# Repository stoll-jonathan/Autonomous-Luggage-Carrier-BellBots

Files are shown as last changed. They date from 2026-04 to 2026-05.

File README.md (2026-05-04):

# BellBot — Autonomous Luggage Carrier

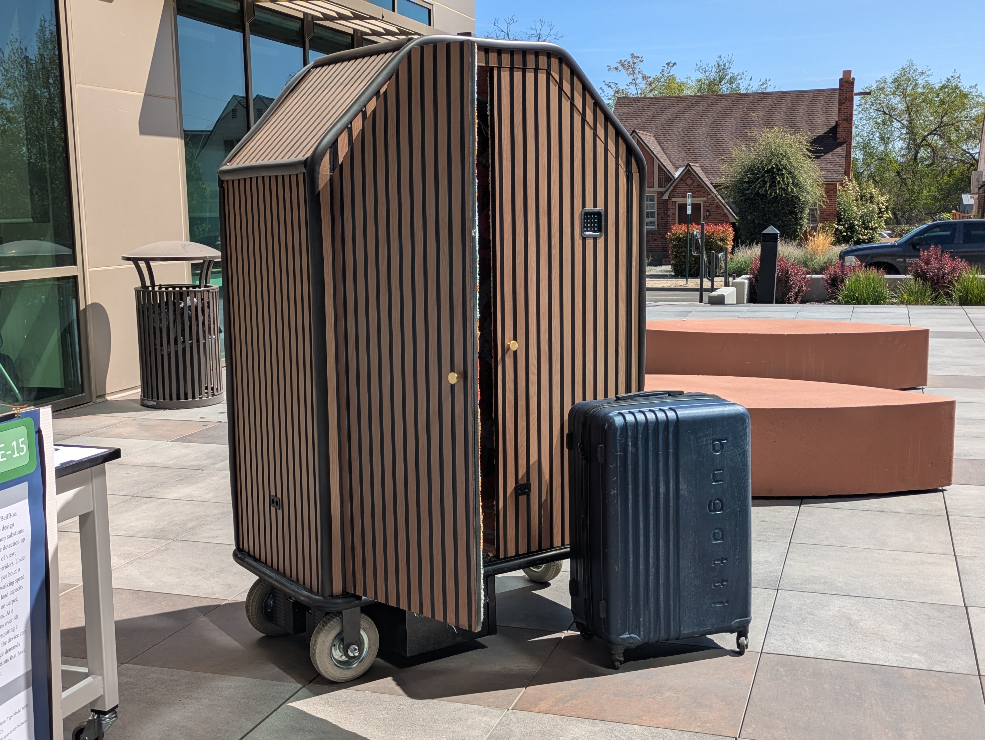
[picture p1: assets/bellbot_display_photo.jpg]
BellBot completed system


> **My role:** I designed and built the complete electronics, sensor integration, and autonomy software for this system. A team of 5 contributed the drive system and fabricated the housing.

---

## Overview

The BellBot autonomous luggage system addresses two pressing challenges in the hotel industry: guest luggage security and bell service operational cost. A guest checks in, their luggage is loaded into BellBot and secured via an electronic locking system, and the cart autonomously navigates to the guest's room, arriving ready to meet them.

With a projected unit cost of ~$2500, BellBot offers a compelling alternative to the ongoing labor cost of human bell staff.

---

## How It Works

BellBot is controlled by an Arduino running a C++ autonomy stack. At the core of the system:

- A **keypad interface** handles guest authentication and program selection
- An array of **ultrasonic sensors** provide obstacle detection to stop the cart safely if something enters its path
- An **electronic locking mechanism** secures the luggage compartment until the correct code is entered at the destination
- A **motor controller** interfaces between the Arduino and the drive system, translating autonomy commands into wheel movement

The system is designed around a simple state machine: the cart accepts a destination program, locks the compartment, navigates autonomously, and waits for authenticated unlocking at the destination.

---

## My Contributions

All code in this repository was written by me. My work on BellBot covered three areas:

**Electronics & Wiring** — Designed and wired the complete electronics system, including the Arduino, motor controller, ultrasonic sensors, keypad, and electronic lock. Designed the electronics enclosure and produced the full system wiring diagram and bill of materials for electronic components.

**Sensor Integration** — Wrote all processing code for the ultrasonic sensor data. Tuned detection thresholds and motor control logic for reliable real-world performance in a corridor environment.

**Autonomy Stack** — Implemented the sensor data processing, keypad input handling, navigation programs, and motor control interface in C++. Designed the demo program suite for testing and demonstration purposes.

> 📂 Full portfolio write-up with circuit diagrams, wiring photos, and CAD files: [sites.google.com/view/JonathanLukeStoll](#)

---

## Demo Programs

The system ships with five navigation programs selectable via keypad at startup. These were designed to test and demonstrate the key movement capabilities of the BellBot device.

| Keystring | Program | Description |
|---|---|---|
| `1972` | Unlock Door | Electronic lock retracts. Compartment can be locked again with any four digits which are not already a stated input code. |
| `#A11` | Stop on Detection | Cart advances until an obstacle is detected by the ultrasonic sensors, then halts |
| `#B22` | Turn Left | Executes a calibrated 90° left turn |
| `#C33` | Turn Right | Executes a calibrated 90° right turn |
| `#D44` | Turn 180 | Executes a full calibrated 180° turn |
| `BBBB` | Move Backward | Reverses for five seconds |

Enter `####` at any time to stop the current program.

---

## Hardware

| Component | Role |
|---|---|
| Arduino Mega | Main computer and autonomy controller |
| Ultrasonic sensors | Obstacle detection |
| Matrix keypad | Guest authentication and program selection |
| Electronic lock | Luggage compartment security |
| Motor controller | Drive system interface |

Full wiring diagram, electronics BOM, and enclosure CAD files available at the portfolio link above.

---

## Acknowledgments

BellBot was a senior capstone project completed by a team of 5 Mechanical Engineering students.

| Contributor | Role |
|---|---|
| Jonathan Stoll | Electronics, sensor integration, autonomy software |
| Colton Hope | Drive system design, housing fabrication |
| Tyler Swanson | 3D CAD models and design drawings, housing fabrication |
| Pedro Lechuga | Housing fabrication |
| Terrance Silva | Design document preparation, presentation of final design |

---

*University of Nevada, Reno · Mechanical Engineering Capstone · 2026*

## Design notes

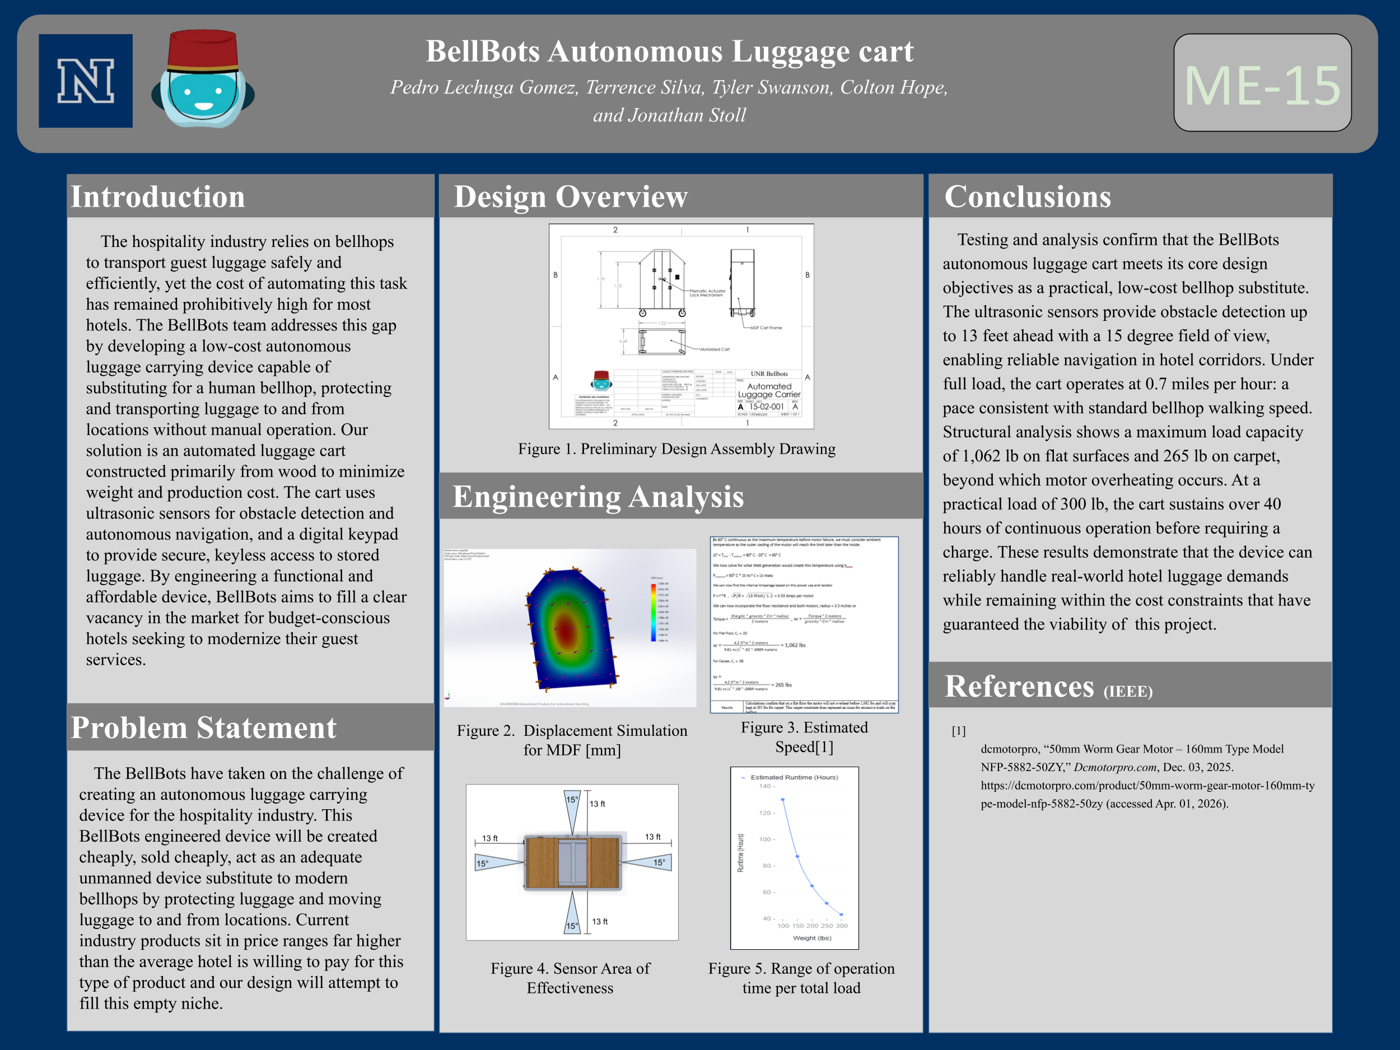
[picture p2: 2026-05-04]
assets/PartE_RG3SQ6_ME-15_Poster.png

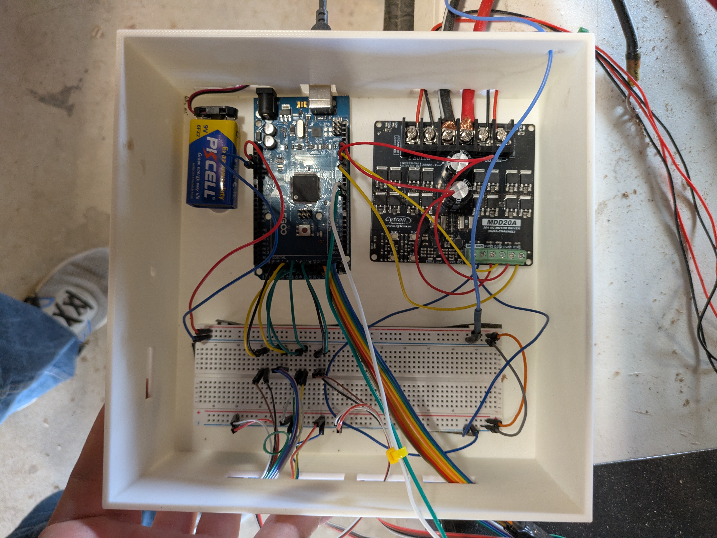
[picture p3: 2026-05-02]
assets/electronics_box_photo.jpg

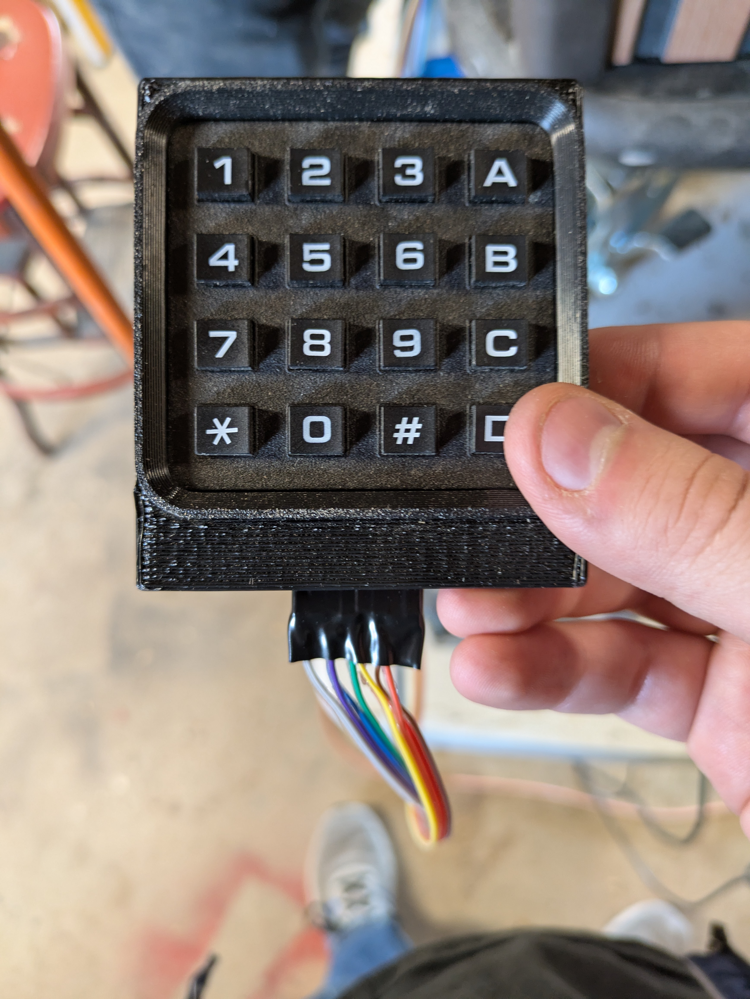
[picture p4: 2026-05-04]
assets/Matrix Keypad.jpg

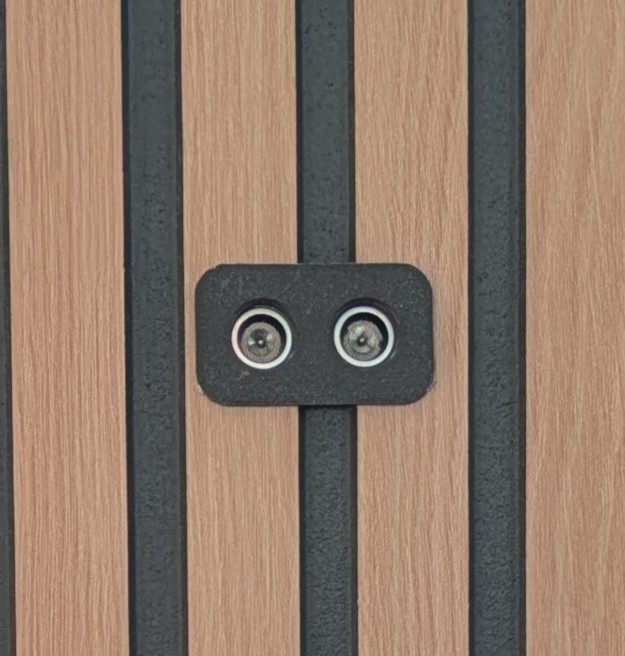
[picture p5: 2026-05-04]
assets/Ultrasonic Sensor.jpg

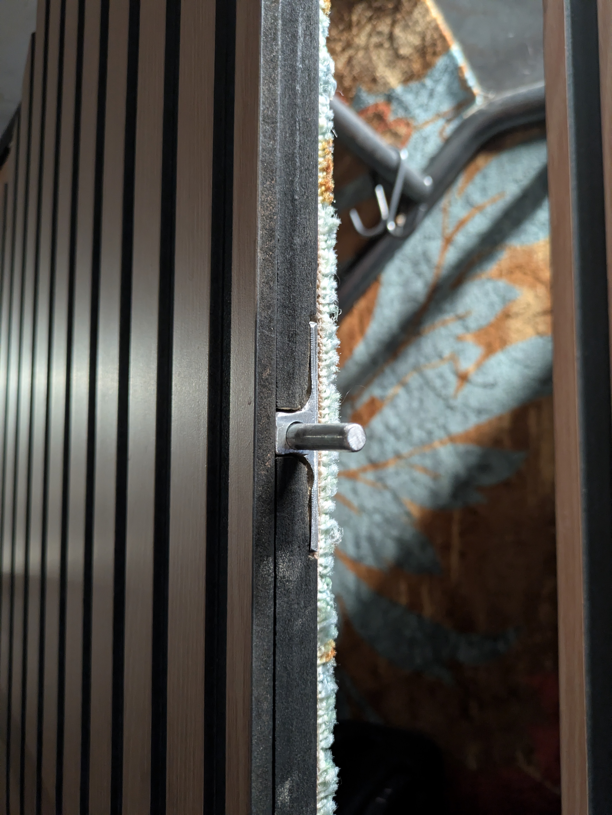
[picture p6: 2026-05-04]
assets/Door lock actuator.jpg

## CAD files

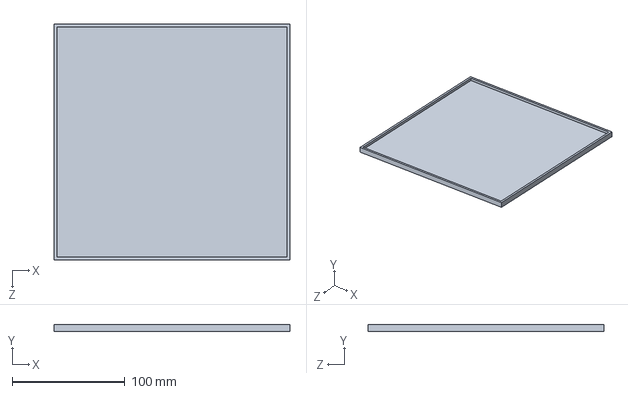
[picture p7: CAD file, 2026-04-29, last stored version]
Electrical Box/Lid.STEP
209.5 x 6.35 x 209.5 mm

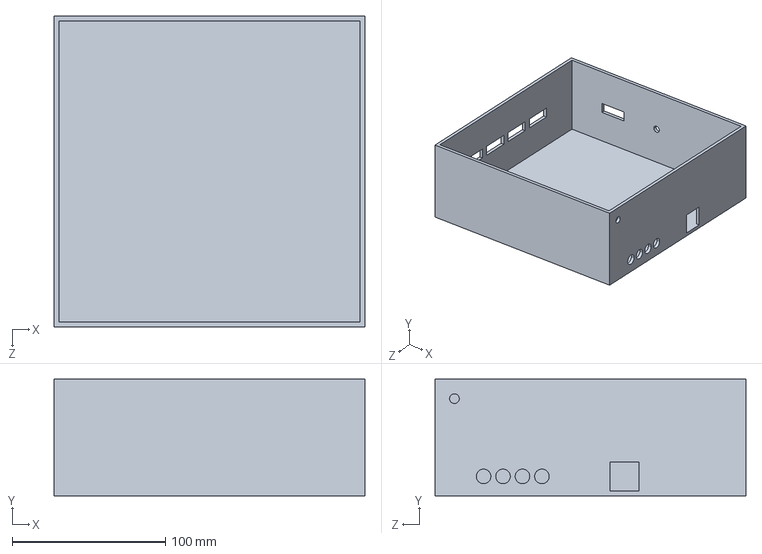
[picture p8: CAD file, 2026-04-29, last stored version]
Electrical Box/Box.STEP
203.2 x 76.2 x 203.2 mm

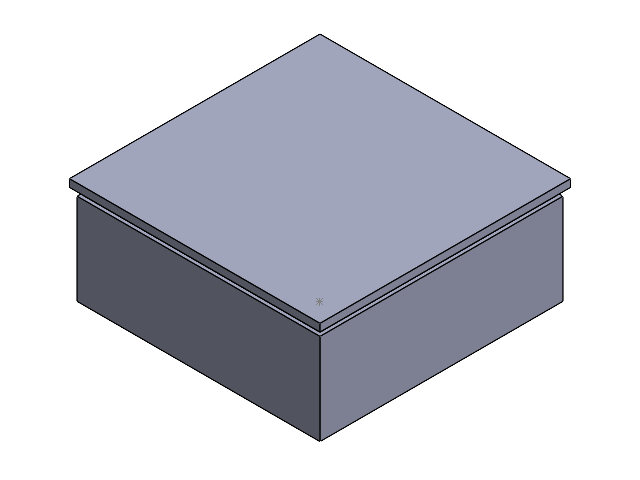
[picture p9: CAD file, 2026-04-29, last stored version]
Electrical Box/Box Assembly.SLDASM
Lid

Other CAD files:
Electrical Box/Box.SLDPRT
Electrical Box/Lid.SLDPRT

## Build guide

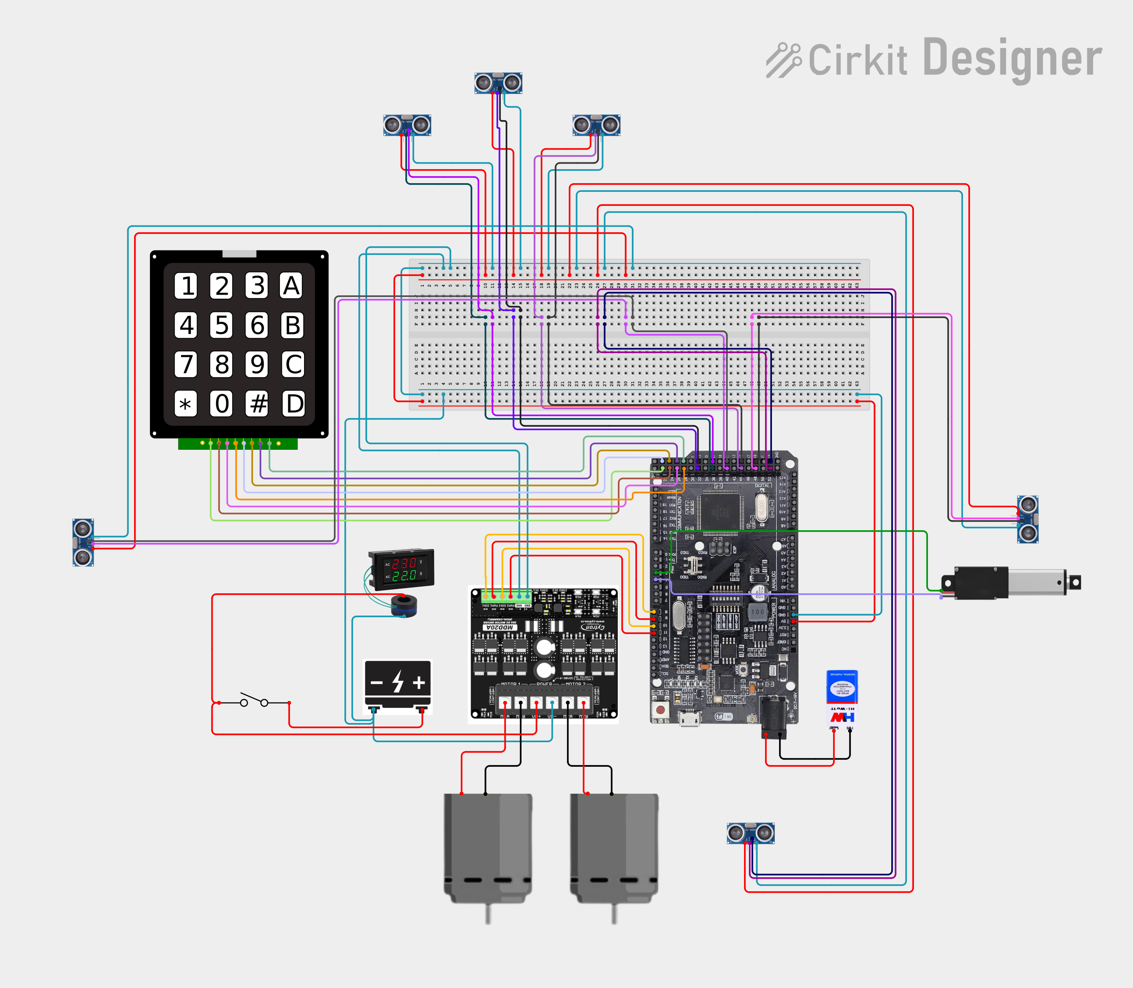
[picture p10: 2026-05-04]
assets/Wiring Diagram.png

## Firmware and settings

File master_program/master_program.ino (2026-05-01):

// BellBots Capstone Project - Autonomous Bellcart System

#include <Keypad.h>

// GENERAL SETUP
bool DISABLED = true;
const int num_demo_programs = 5;
const char* demo_program_names[num_demo_programs] = {
  "Stop on Detection",
  "Turn Left",
  "Turn Right",
  "Turn 180",
  "Move Backward Five Seconds"
};

// KEYPAD SETUP
const int ROW_NUM = 4;
const int COLUMN_NUM = 4;

const char keys[ROW_NUM][COLUMN_NUM] = {
  {'1','2','3', 'A'},
  {'4','5','6', 'B'},
  {'7','8','9', 'C'},
  {'*','0','#', 'D'}
};

const byte row_pins[ROW_NUM] = {23, 25, 27, 29};
const byte column_pins[COLUMN_NUM] = {22, 24, 26, 28};
Keypad keypad = Keypad( makeKeymap(keys), row_pins, column_pins, ROW_NUM, COLUMN_NUM );

const int CODE_LENGTH = 4;
const unsigned long TIMEOUT_MS = 2000; // allow 2 seconds between keypresses before entry window resets

const char correct_code[CODE_LENGTH] = {'1', '9', '7', '2'}; // hardcoded for demo purposes
const char disable_program_code[CODE_LENGTH] = {'#', '#', '#', '#'};
const char demo_program_codes[num_demo_programs][CODE_LENGTH] = { {'#', 'A', '1', '1'}, {'#', 'B', '2', '2'}, {'#', 'C', '3', '3'}, {'#', 'D', '4', '4'}, {'B', 'B', 'B', 'B'} };
char curr_program_code[CODE_LENGTH] = {0, 0, 0, 0};

char entered_code[CODE_LENGTH];
int code_index = 0;
unsigned long last_keypress_time = 0;


// ULTRASONIC (PROXIMITY) SENSOR SETUP
const int TRIGGER_PINS[4] = {36, 44, 40, 48}; // front left (from inside cart), front right (from inside cart), left (across from doors), right (doors)
const int ECHO_PINS[4] = {37, 45, 41, 49};
const int THRESHOLD_INCHES = 12;


// MOTOR SETUP
const int DIR_PINS[2] = {8, 10}; // right, left
const int PWM_PINS[2] = {9, 11}; // right, left
const int turnDuration = 10000; // ms
const int leftBaseSpeed = 230; // physical imperfection: motors run at different speeds by default, these vars compensate for that
const int rightBaseSpeed = 230;


// DOOR LOCK SETUP
bool doorLocked = true;
const int actuatorPins[2] = {3, 4};


// Function Prototypes
void stopOnDetection(long duration[], long inches[]);
void demoTurnLeft();
void demoTurnRight();
void demoTurn180();
void moveBackwardFiveSeconds();

bool doorCodesAreEqual(char code1[], char code2[], int length);
bool isValidProgramCode(char code[]);
void lockDoor();
void unlockDoor();
bool forwardPathClear(long duration[], long inches[]);
bool leftPathClear(long duration[], long inches[]);
bool rightPathClear(long duration[], long inches[]);
void readSensors(long duration[], long inches[]);
long microsecondsToInches(long microseconds);

void moveForward(long duration[], long inches[]);
void stopCart();
void turnLeft();
void turnRight();
void turn180();
void leftOnDetection(long duration[], long inches[]);
void rightOnDetection(long duration[], long inches[]);

void testSensors(long duration[], long inches[]);


void setup() {
  Serial.begin(9600);

  for (int i = 0; i < 4; i++) {
    pinMode(TRIGGER_PINS[i], OUTPUT);
    pinMode(ECHO_PINS[i], INPUT);
  }

  for (int i = 0; i < 2; i++) {
    pinMode(DIR_PINS[i], OUTPUT);
    pinMode(PWM_PINS[i], OUTPUT);
  }

  pinMode(actuatorPins[0], OUTPUT);
  pinMode(actuatorPins[1], OUTPUT);

  Serial.println("Initializing Program.");
}

void loop() {

  // KEYPAD AND DOOR LOGIC
  char key = keypad.getKey();

  // Reset if too much time has passed since the last keypress
  unsigned long now = millis();
  if (code_index > 0 && (now - last_keypress_time) > TIMEOUT_MS) {
    Serial.println("Timeout - restarting entry.");
    code_index = 0;
  }
    
  if (key) {
    entered_code[code_index] = key;
    code_index++;
    last_keypress_time = now;

    Serial.print("Key pressed: ");
    Serial.println(key);

    if (code_index == CODE_LENGTH) {
      Serial.print("Code entered: ");
      for (int i = 0; i < CODE_LENGTH; i++) {
        Serial.print(entered_code[i]);
      }
      Serial.println();

      // Door is unlocked if unlock code is entered, locked if any other code is entered
      if (doorCodesAreEqual(entered_code, correct_code, CODE_LENGTH)) {
        Serial.println("Unlocking Door...");
        unlockDoor();
        Serial.println("Door Unlocked.");
        Serial.println();
      }
      else {
        Serial.println("Locking Door...");
        lockDoor();
        Serial.println("Door Locked.");
        Serial.println();
      }

      // Software killswitch: entering the disable_program_code stops all cart movement until a new demo program is selected
      if (doorCodesAreEqual(entered_code, disable_program_code, CODE_LENGTH)) {
        Serial.println("Program Stopped");
        Serial.println();
        DISABLED = true;
      }
      else if (isValidProgramCode(entered_code)) {
        DISABLED = false;
        memcpy(curr_program_code, entered_code, CODE_LENGTH);

        for (int i = 0; i < num_demo_programs; i++) {
          if (doorCodesAreEqual(entered_code, demo_program_codes[i], CODE_LENGTH)) {
            Serial.print("Starting demo program: ");
            Serial.println(demo_program_names[i]);
            break;
          }
        }
      }

      code_index = 0; // Reset for next entry
    }
  }

  
  // SENSOR AND MOVEMENT LOGIC
  if (DISABLED) {
    stopCart();
    return;
  }
  
  long duration[4], inches[4];
  readSensors(duration, inches);

  if (doorCodesAreEqual(curr_program_code, demo_program_codes[0], CODE_LENGTH)) {
    stopOnDetection(duration, inches);
  }
  else if (doorCodesAreEqual(curr_program_code, demo_program_codes[1], CODE_LENGTH)) {
    demoTurnLeft();
  }
  else if (doorCodesAreEqual(curr_program_code, demo_program_codes[2], CODE_LENGTH)) {
    demoTurnRight();
  }
  else if (doorCodesAreEqual(curr_program_code, demo_program_codes[3], CODE_LENGTH)) {
    demoTurn180();
  }
  else if (doorCodesAreEqual(curr_program_code, demo_program_codes[4], CODE_LENGTH)) {
    moveBackwardFiveSeconds();
  }
  
}


// Demonstration Programs
void stopOnDetection(long duration[], long inches[]) {
  // TASK: move forward until an object is detected, then stop

  if (forwardPathClear(duration, inches)) {
    Serial.println("Free to move");

    moveForward(duration, inches);
  }
  else {
    Serial.print("Object detected ");
    Serial.print(inches[0]);
    Serial.println("in away");

    stopCart();

    DISABLED = true; // return to program selection menu
  }
}

void demoTurnLeft() {
  turnLeft();

  DISABLED = true; // return to program selection menu
}

void demoTurnRight() {
  turnRight();

  DISABLED = true; // return to program selection menu
}

void demoTurn180() {
  turn180();

  DISABLED = true; // return to program selection menu
}

void moveBackwardFiveSeconds() {
  digitalWrite(DIR_PINS[0], LOW); // HIGH -> forward, LOW -> backward
  digitalWrite(DIR_PINS[1], LOW);

  analogWrite(PWM_PINS[0], leftBaseSpeed);
  analogWrite(PWM_PINS[1], rightBaseSpeed);

  delay(5000);
  stopCart();

  DISABLED = true; // return to program selection menu
}


// Helper Functions
bool doorCodesAreEqual(char code1[], char code2[], int length) {
  for (int i = 0; i < length; i++) {
    if (code1[i] != code2[i]) 
      return false;
  }
  return true;
}

bool isValidProgramCode(char code[]) {
  for (int i = 0; i < num_demo_programs; i++) {
    if (doorCodesAreEqual(code, demo_program_codes[i], CODE_LENGTH)) {
      return true;
    }
  }
  return false;
}

void lockDoor() {
  stopCart();
  
  if (!doorLocked) { // only lock if door is currently unlocked, otherwise skip
    // move actuator out
    digitalWrite(actuatorPins[0], LOW);
    digitalWrite(actuatorPins[1], HIGH);

    delay(7000); // takes 5 seconds for actuator to extend
  }
  doorLocked = true;
}

void unlockDoor() {
  stopCart();
  
  if (doorLocked) { // only unlock if door is currently locked, otherwise skip
    // move actuator in
    digitalWrite(actuatorPins[0], HIGH);
    digitalWrite(actuatorPins[1], LOW);

    delay(7000); // takes 5 seconds for actuator to return
  }
  doorLocked = false;
}

bool forwardPathClear(long duration[], long inches[]) {
  return ( (duration[0] == 0 || inches[0] > THRESHOLD_INCHES) && (duration[1] == 0 || inches[1] > THRESHOLD_INCHES) );
}

bool leftPathClear(long duration[], long inches[]) {
  return (duration[2] == 0 || inches[2] > THRESHOLD_INCHES);
}

bool rightPathClear(long duration[], long inches[]) {
  return (duration[3] == 0 || inches[3] > THRESHOLD_INCHES);
}

void readSensors(long duration[], long inches[]) {
  for (int i = 0; i < 4; i++) {
    digitalWrite(TRIGGER_PINS[i], LOW);

    delayMicroseconds(2);

    digitalWrite(TRIGGER_PINS[i], HIGH);

    delayMicroseconds(10);

    digitalWrite(TRIGGER_PINS[i], LOW);

    duration[i] = pulseIn(ECHO_PINS[i], HIGH, 6000);
    inches[i] = microsecondsToInches(duration[i]);
  }

}

long microsecondsToInches(long microseconds) {
  // According to Parallax's datasheet for the PING))), there are 73.746
  // microseconds per inch (i.e. sound travels at 1130 feet per second).
  // This gives the distance travelled by the ping, outbound and return,
  // so we divide by 2 to get the distance of the obstacle.
  // See: https://www.parallax.com/package/ping-ultrasonic-distance-sensor-downloads/
  return microseconds / 74 / 2;
}


// Movement Programs
void moveForward(long duration[], long inches[]) {
  // Cart will course-correct based on differences in detected distances between the two front sensors.
  
  const float GAIN = 1.0;
  const int maxRange = 96; // inches
  
  int leftSpeed, rightSpeed;
  
  // Only correct if both sensors got a valid reading and both are within a reliable range
  if (duration[0] != 0 && duration[1] != 0 && inches[0] < maxRange && inches[1] < maxRange) {
    int correction = constrain((inches[1] - inches[0]) * GAIN, -50, 50); // 0 = front left, 1 = front right

    leftSpeed = constrain(leftBaseSpeed - correction, 0, 255);
    rightSpeed = constrain(rightBaseSpeed + correction, 0, 255);
  } 
  else {
    leftSpeed = leftBaseSpeed;
    rightSpeed = rightBaseSpeed;
  }
  
  digitalWrite(DIR_PINS[0], HIGH); // HIGH -> forward, LOW -> backward
  digitalWrite(DIR_PINS[1], HIGH);

  analogWrite(PWM_PINS[0], leftSpeed);
  analogWrite(PWM_PINS[1], rightSpeed);
}

void stopCart() {
  analogWrite(PWM_PINS[0], 0);
  analogWrite(PWM_PINS[1], 0);
}

void turnLeft() {
  stopCart();
  delay(1000);
  
  digitalWrite(DIR_PINS[0], HIGH); // HIGH -> forward, LOW -> backward
  digitalWrite(DIR_PINS[1], LOW);
  
  // move motors opposite directions
  analogWrite(PWM_PINS[0], leftBaseSpeed);
  analogWrite(PWM_PINS[1], rightBaseSpeed);

  delay(turnDuration);
  stopCart();
}

void turnRight() {
  stopCart();
  delay(1000);

  digitalWrite(DIR_PINS[0], LOW); // HIGH -> forward, LOW -> backward
  digitalWrite(DIR_PINS[1], HIGH);

  // move motors in opposite directions
  analogWrite(PWM_PINS[0], leftBaseSpeed);
  analogWrite(PWM_PINS[1], rightBaseSpeed);

  delay(turnDuration);
  stopCart();
}

void turn180() {
  stopCart();
  delay(1000);
  
  digitalWrite(DIR_PINS[0], LOW); // HIGH -> forward, LOW -> backward
  digitalWrite(DIR_PINS[1], HIGH);

  // move right motor faster than the left
  analogWrite(PWM_PINS[0], leftBaseSpeed);
  analogWrite(PWM_PINS[1], rightBaseSpeed);

  delay(2*turnDuration);
  stopCart();
}

void leftOnDetection(long duration[], long inches[]) {
  // TASK: move forward until an object is detected, then turn left 90° and stop

  if (forwardPathClear(duration, inches)) {
    Serial.println("Free to move");

    moveForward(duration, inches);
  }
  else {
    Serial.print("Object detected ");
    Serial.print(inches[0]);
    Serial.println("in away");

    turnLeft();
  }
}

void rightOnDetection(long duration[], long inches[]) {
  // TASK: move forward until an object is detected, then turn right 90° and stop

  if (forwardPathClear(duration, inches)) {
    Serial.println("Free to move");

    moveForward(duration, inches);
  }
  else {
    Serial.print("Object detected ");
    Serial.print(inches[0]);
    Serial.println("in away");

    turnRight();
  }
}


// For Testing Purposes
void testSensors(long duration[], long inches[]) {
  readSensors(duration, inches);

  Serial.println(inches[0]); // front left (from inside cart)
  Serial.println(inches[1]); // front right (from inside cart)
  Serial.println(inches[2]); // left (across from doors)
  Serial.println(inches[3]); // right (doors)
  Serial.println();
}

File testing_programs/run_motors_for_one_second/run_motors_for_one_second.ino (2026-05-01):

// BellBots Capstone Project - Autonomous Bellcart System

// MOTOR SETUP
const int DIR_PINS[2] = {8, 10}; // right, left
const int PWM_PINS[2] = {9, 11}; // right, lef

void setup() {
  Serial.begin(9600);

  for (int i = 0; i < 2; i++) {
    pinMode(DIR_PINS[i], OUTPUT);
    pinMode(PWM_PINS[i], OUTPUT);
  }

  Serial.println("Initializing Program.");
}

void loop() {
  if (Serial.available() > 0) {
    char key = Serial.read();

    if (key == 'a') {
      moveForward();
      delay(1000);
      stopCart();
    }
  }
}


void moveForward() {
  digitalWrite(DIR_PINS[0], HIGH); // HIGH -> forward, LOW -> backward
  digitalWrite(DIR_PINS[1], HIGH);

  analogWrite(PWM_PINS[0], 255);   // 0–255
  analogWrite(PWM_PINS[1], 255);
}

void stopCart() {
  analogWrite(PWM_PINS[0], 0);
  analogWrite(PWM_PINS[1], 0);
}

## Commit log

2026-04-29 added demo programs and fixed turning logic
    [test.ino]
2026-04-30 added brief pause to turn functions to allow motors to come to a stop
2026-04-30 increased default wheel speed
2026-05-02 remade README and cleaned up file structure
    [Box Assembly.SLDASM, Box.SLDPRT, Box.STEP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]
2026-05-04 added wiring diagram to assets
